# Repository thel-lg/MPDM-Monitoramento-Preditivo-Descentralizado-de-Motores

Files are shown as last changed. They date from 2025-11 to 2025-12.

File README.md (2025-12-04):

# MPDM - Monitoramento Preditivo de Motores Elétricos





Este repositório contém o firmware e documentação do **MPDM**, um sistema IOT desenvolvido como Trabalho de Conclusão de Curso (TCC) focado na Indústria 4.0 e Manutenção Preditiva.

O sistema realiza a leitura de grandezas físicas críticas de motores elétricos, transmite via LoRa (Long Range) e apresenta os dados em uma Interface Homem-Máquina (IHM) portátil com capacidade de armazenamento histórico.

## 👨‍💻 Equipe de Desenvolvimento

Este projeto foi desenvolvido por:
* **Gustavo Santana Nascimento**
* **Lucas Santos Gama**
* **Nicole da Silva Nunes Pitombeira**
* **Polyanna Silva Borges**

---

## 📐 Arquitetura do Sistema

O projeto é dividido em dois módulos baseados no microcontrolador ESP32:

### 1. Módulo Transmissor (Sensor Node)
Responsável pela aquisição de dados e transmissão sem fio.
* **Processamento:** Leitura de sensores e fusão de dados.
* **Estado:** Máquina de estados (Standby / Transmitting) para economia de energia.
* **Feedback:** LED RGB para indicação visual de status (Erro, Conexão, Leitura).

### 2. Módulo Receptor (Gateway/IHM)
Responsável pelo recebimento, processamento, exibição e armazenamento.
* **Interface:** Display TFT colorido com navegação por menus e gráficos em tempo real.
* **Datalogger:** Gravação de dados em Cartão SD (CSV) com timestamp preciso (RTC).
* **Diagnóstico:** Sistema de alertas visuais e sonoros para falhas de hardware (LoRa, RTC, SD).

## 🛠 Hardware e Componentes

### Sensores e Atuadores
* **Microcontrolador:** ESP32 (DevKit V1)
* **Vibração/Acelerômetro:** BMI160 (Eixos X, Y, Z e RMS)
* **Corrente AC:** SCT-013 (Não invasivo)
* **Temperatura:** DS18B20 (Blindado)
* **Comunicação:** Módulos LoRa SX1278 (433MHz)
* **Armazenamento:** Módulo Micro SD Card SPI
* **Relógio de Tempo Real:** RTC DS3231 (I2C)
* **Display:** TFT 1.8" ST7735 (SPI)

### Pinagem Principal (Definições)

| Componente | Transmissor (GPIO) | Receptor (GPIO) |
| :--- | :--- | :--- |
| **LoRa (SS/RST/DIO0)** | 5 / 17 / 16 | 5 / 17 / 16 |
| **SPI (SCK/MISO/MOSI)** | Padrão VSPI | 18 / 19 / 23 |
| **Display (CS/DC/RST)** | N/A | 15 / 4 / 25 |
| **SD Card (CS)** | N/A | 13 |
| **I2C (SDA/SCL)** | 21 / 22 | 21 / 22 |
| **LEDs Status / Buzzer** | 25, 26, 33 | 14 (Buzzer) |

## 💻 Funcionalidades do Firmware

### Transmissor
* Leitura de sensores com tratamento de erros (`StatusType Enum`).
* Priorização de status via LED RGB (Azul=TX, Vermelho=Erro, Verde=OK).
* Protocolo de envio de estrutura binária (`struct DadosSensores`) para otimizar o payload LoRa.

### Receptor
* **Menu Interativo:** Navegação por botões físicos (Set, Dir, Esq/Analog).
* **Monitoramento de Saúde:** Watchdog via software para LoRa, RTC e SD Card.
* **Algoritmo de Suavização:** Filtro Exponencial (Alpha 0.8) para estabilização de leitura.
* **Calibração:** Modo dedicado para tara de sensores de vibração e corrente.
* **Segurança:** Sistema de arquivos robusto (`iniciarSDCard_Seguro`) para evitar corrupção de dados.

## 📚 Bibliotecas Utilizadas

* `LoRa` (Sandeep Mistry)
* `Adafruit_GFX` & `Adafruit_ST7735`
* `RTClib` (Adafruit)
* `SPI` & `Wire` (Nativas)
* `SD` & `FS` (Nativas ESP32)

## 🚀 Como Executar

1.  Instale o **Arduino IDE** ou **PlatformIO**.
2.  Instale as bibliotecas listadas acima via Gerenciador de Bibliotecas.
3.  Configure a placa como "DOIT ESP32 DEVKIT V1".
4.  Carregue o código da pasta `/Transmissor` no módulo sensor.
5.  Carregue o código da pasta `/Receptor` no módulo IHM.

---

## 🎓 Agradecimentos Especiais

Gostaríamos de agradecer a todos que tornaram este projeto possível:

* **Orientador:** Prof. Eduardo Félix Pereira, pela orientação técnica.
* **Professores:** Jurandir Sá dos Santos, Ronaldo Oliveira, Juliana da Silva e Sérgio Caldeira, pelo auxílio na elaboração técnica.
* **Escola SENAI “Mariano Ferraz”:** Pela infraestrutura e formação técnica.
* **Banca Examinadora:** Pela presença e pelas valiosas considerações.

---
*Projeto desenvolvido para fins acadêmicos - Curso Técnico em Eletroeletrônica - 2025.*

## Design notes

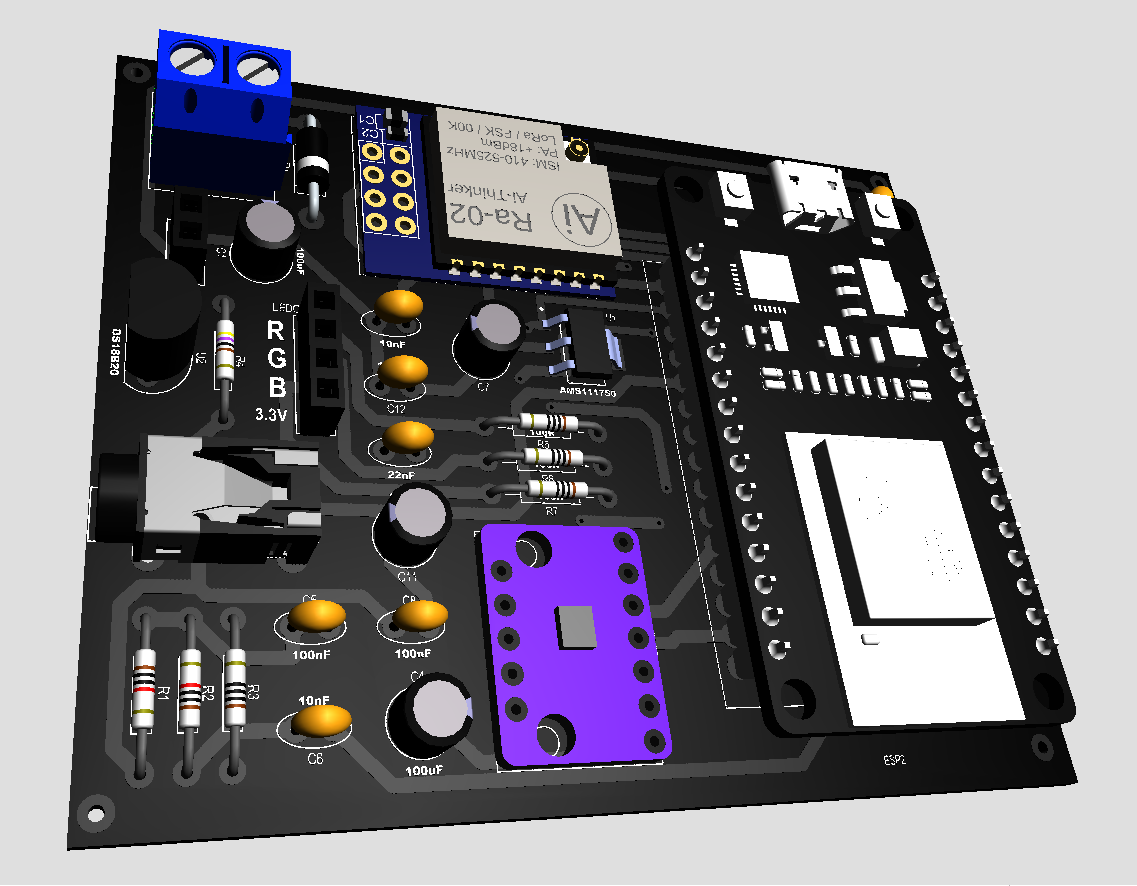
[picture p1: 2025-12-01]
Pci/Capturar.PNG

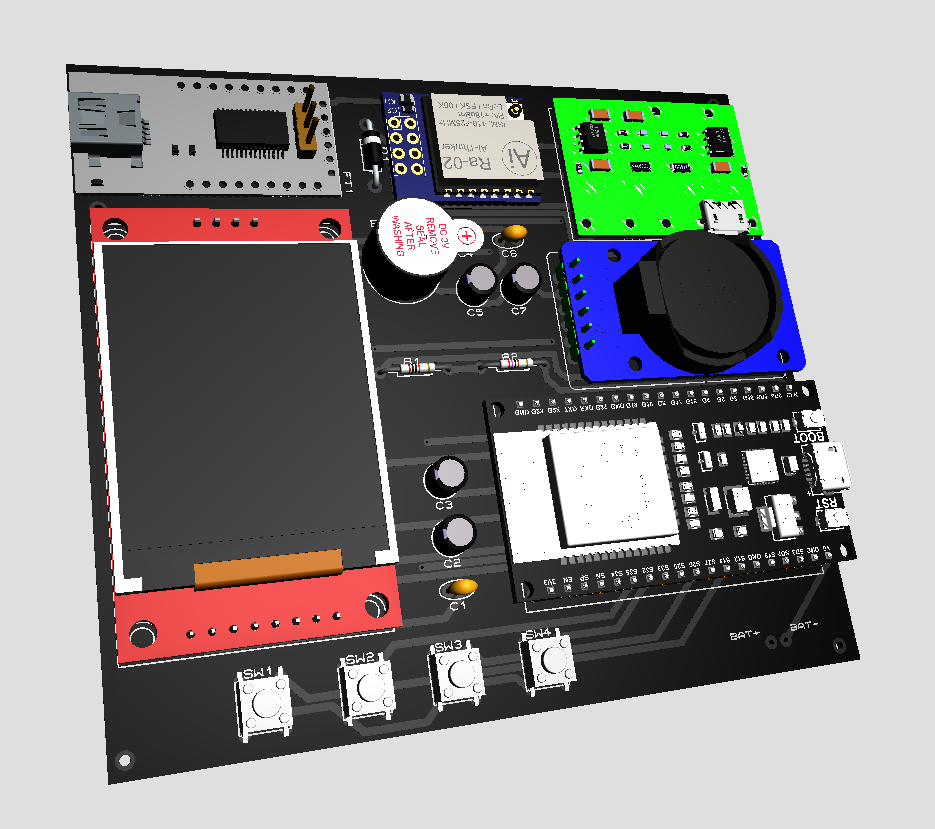
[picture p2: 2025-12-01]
Pci/CapturaQr.PNG

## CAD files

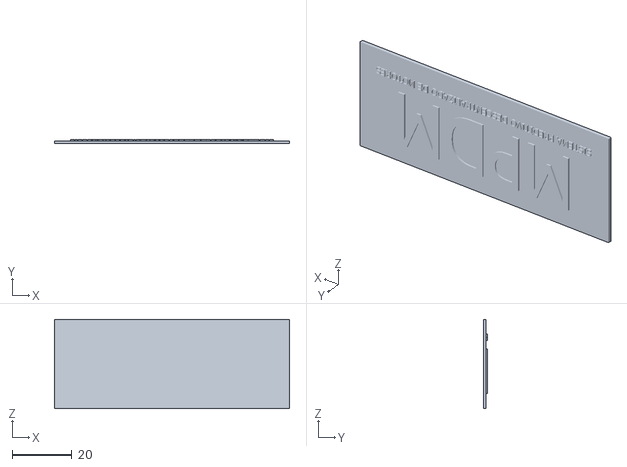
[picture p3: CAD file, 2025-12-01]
Cases3D/Case_Receptora/logoR.stl
79.0 x 1.50 x 30.0

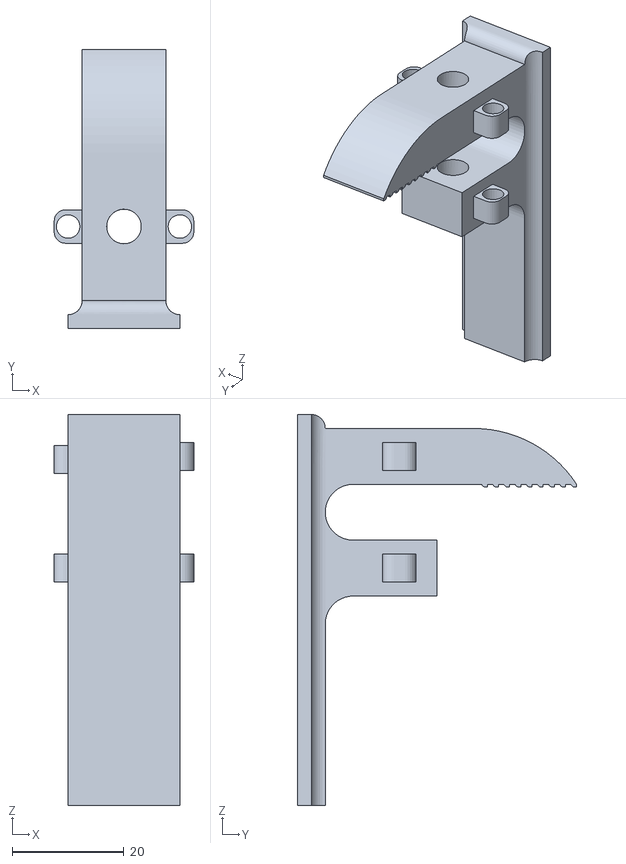
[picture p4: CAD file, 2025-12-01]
Cases3D/Case_Transmissora/Garra.stl
25.0 x 50.0 x 70.0

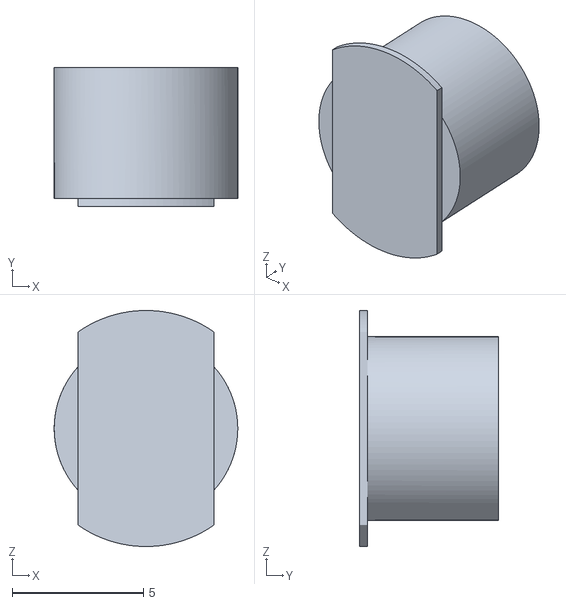
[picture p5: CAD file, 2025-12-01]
Cases3D/Case_Receptora/button.stl
7.00 x 5.30 x 9.00

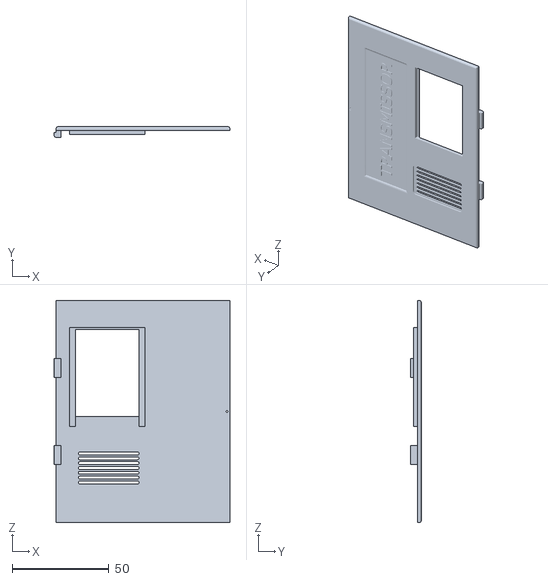
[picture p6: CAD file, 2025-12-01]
Cases3D/Case_Transmissora/Tampatransmissor.stl
91.0 x 5.50 x 115.0

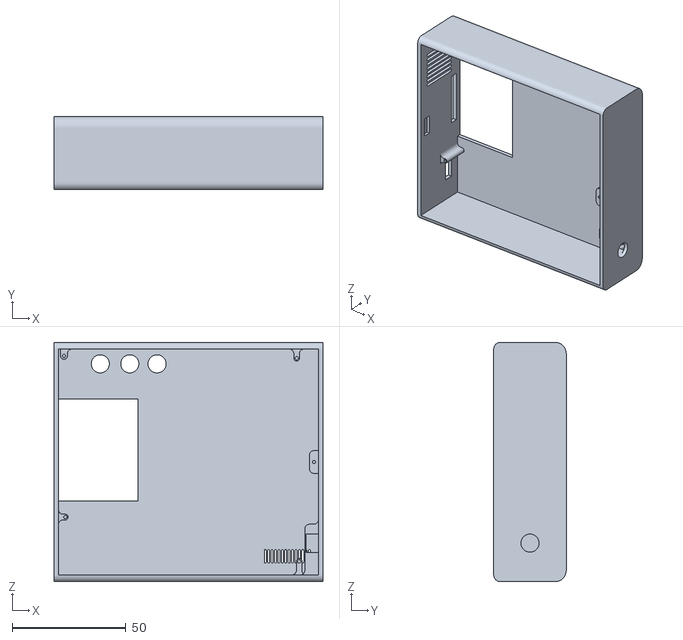
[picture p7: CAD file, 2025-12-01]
Cases3D/Case_Receptora/casereceptora.stl
118.5 x 32.0 x 105.5

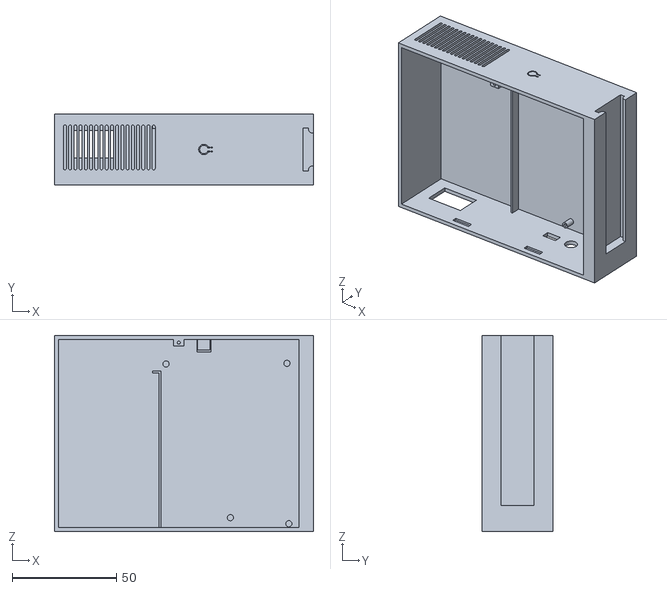
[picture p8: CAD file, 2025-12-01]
Cases3D/Case_Transmissora/transmissor.stl
124.0 x 34.0 x 94.0

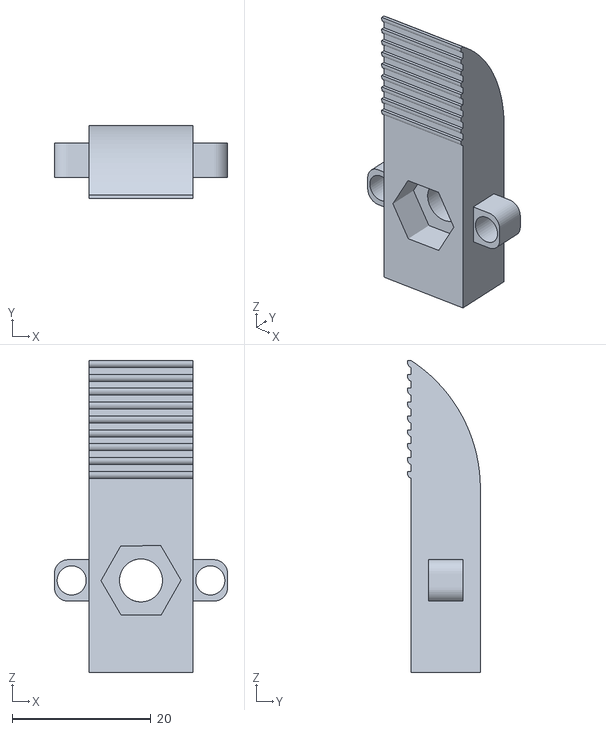
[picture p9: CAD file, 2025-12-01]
Cases3D/Case_Transmissora/garrasolta.stl
25.0 x 10.5 x 45.0

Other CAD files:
Cases3D/Case_Receptora/button.ipt
Cases3D/Case_Receptora/casereceptora.ipt
Cases3D/Case_Receptora/logoR.ipt
Cases3D/Case_Transmissora/Garra.ipt
Cases3D/Case_Transmissora/Pino.ipt
Cases3D/Case_Transmissora/Tampatransmissor.ipt
Cases3D/Case_Transmissora/garrasolta.ipt
Cases3D/Case_Transmissora/transmissor.ipt

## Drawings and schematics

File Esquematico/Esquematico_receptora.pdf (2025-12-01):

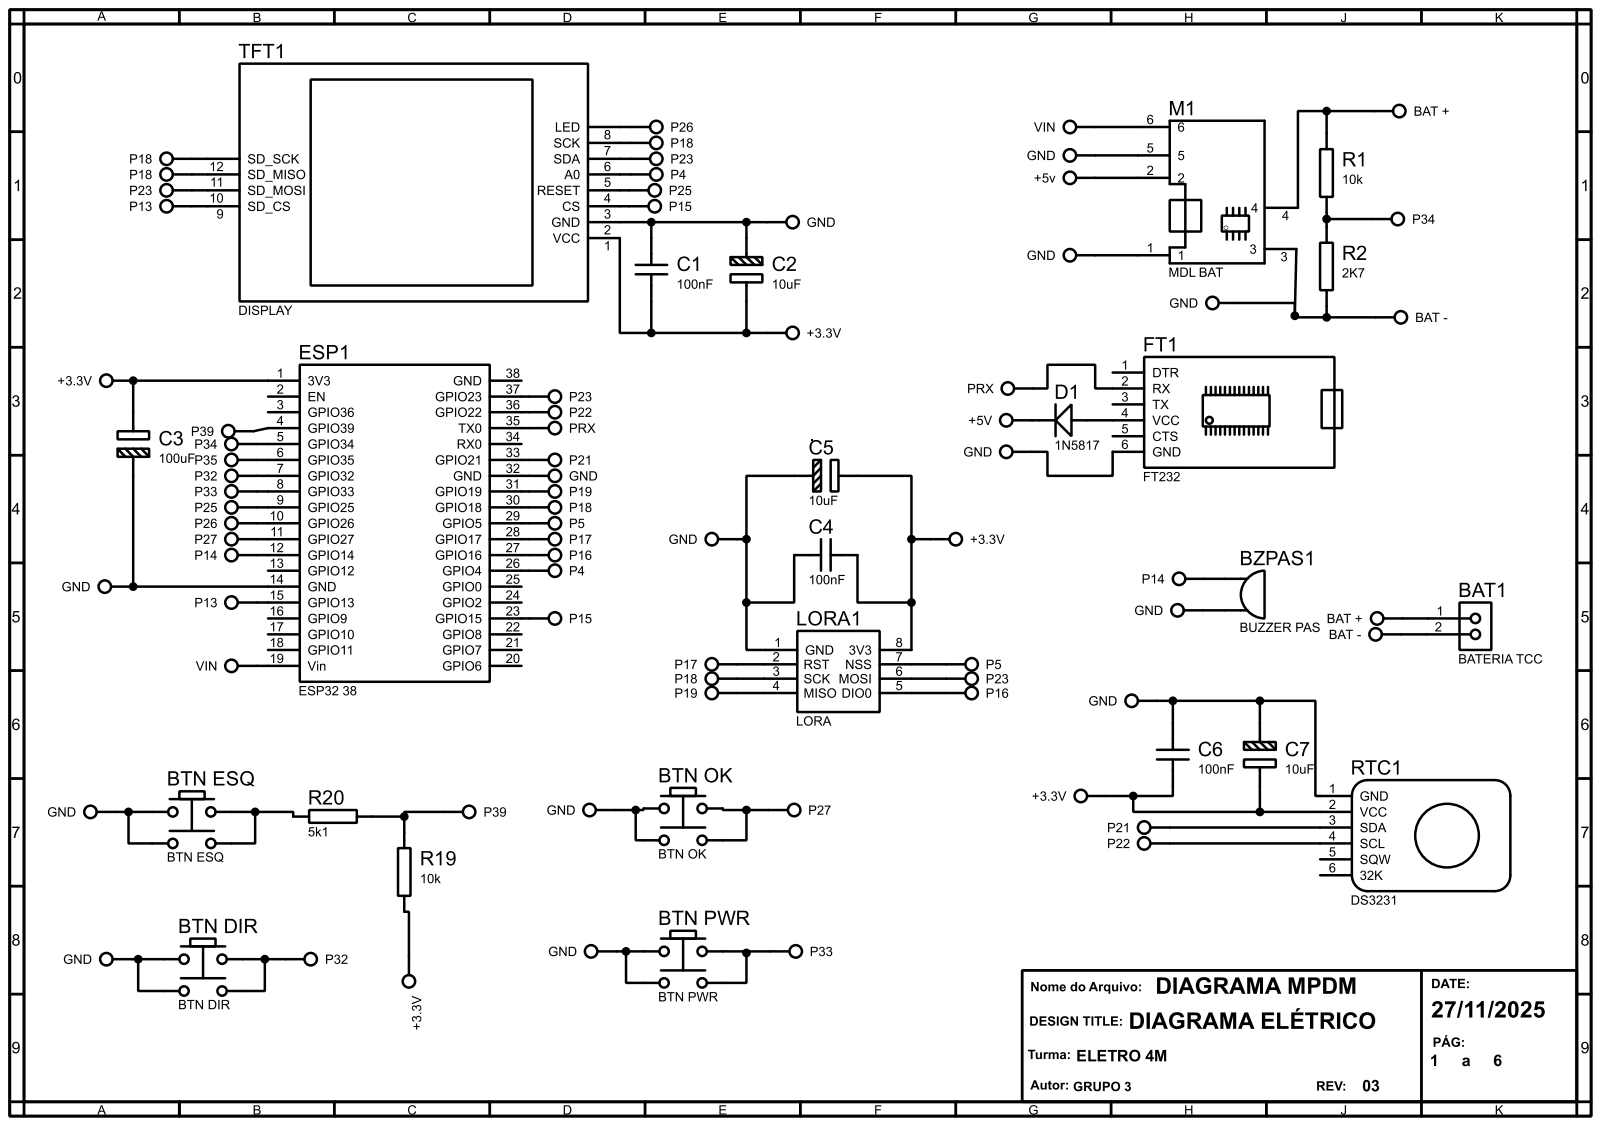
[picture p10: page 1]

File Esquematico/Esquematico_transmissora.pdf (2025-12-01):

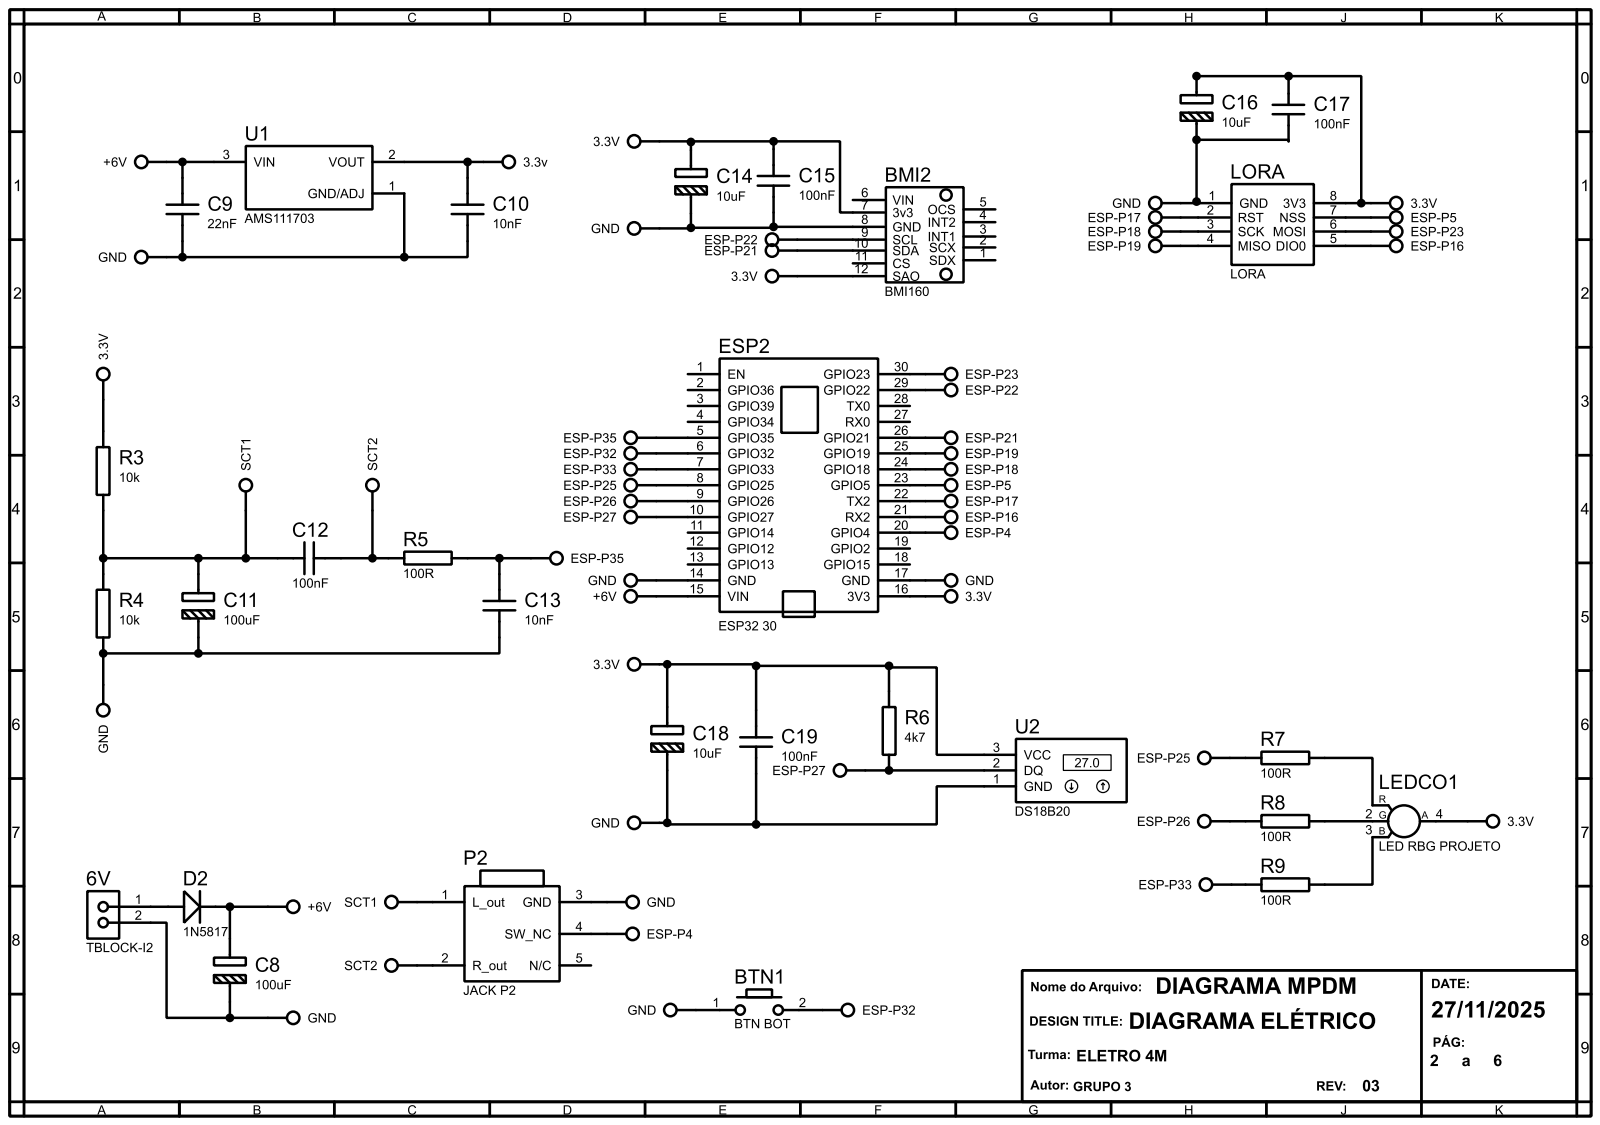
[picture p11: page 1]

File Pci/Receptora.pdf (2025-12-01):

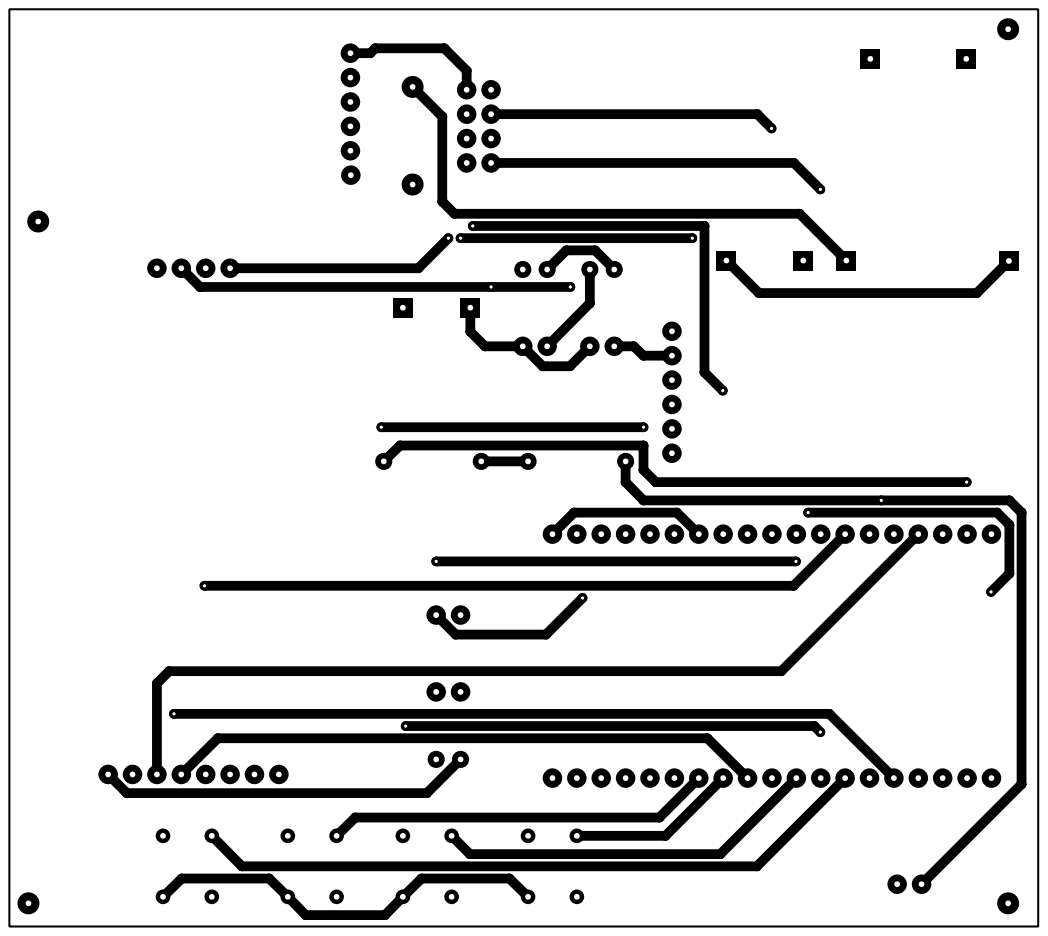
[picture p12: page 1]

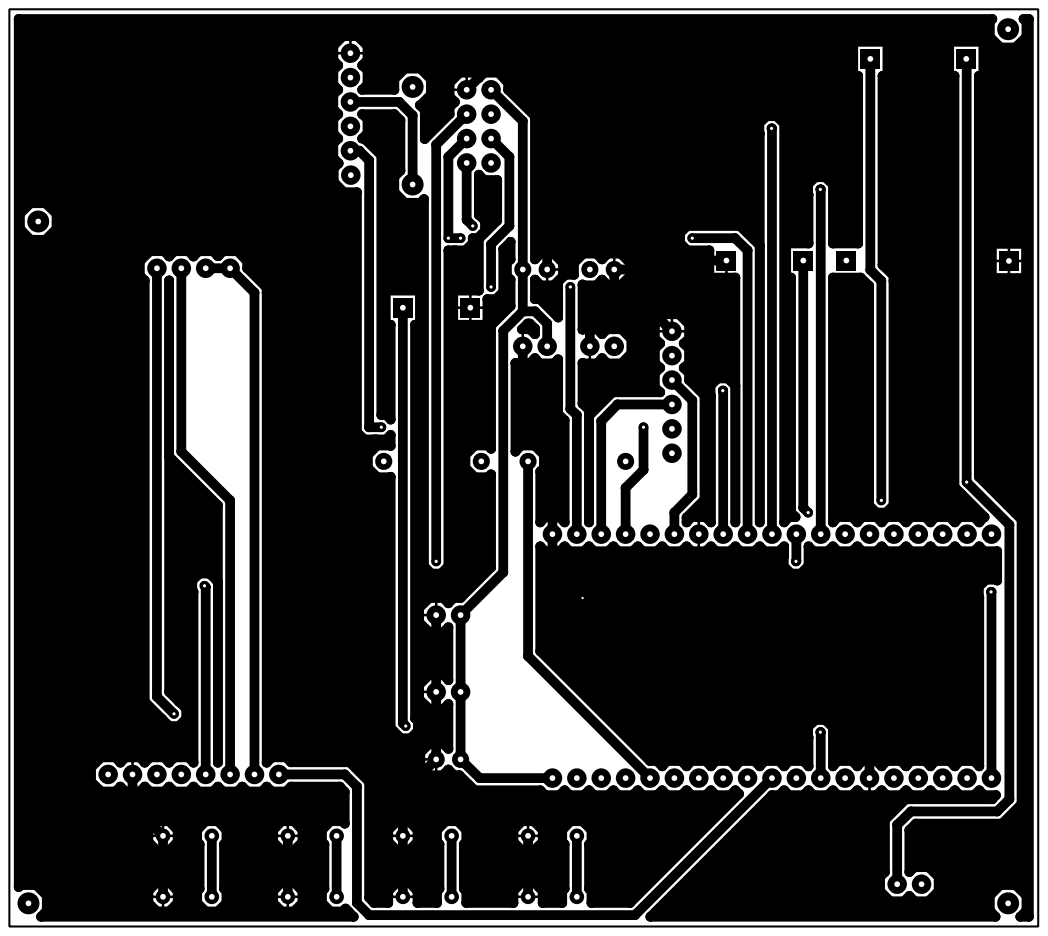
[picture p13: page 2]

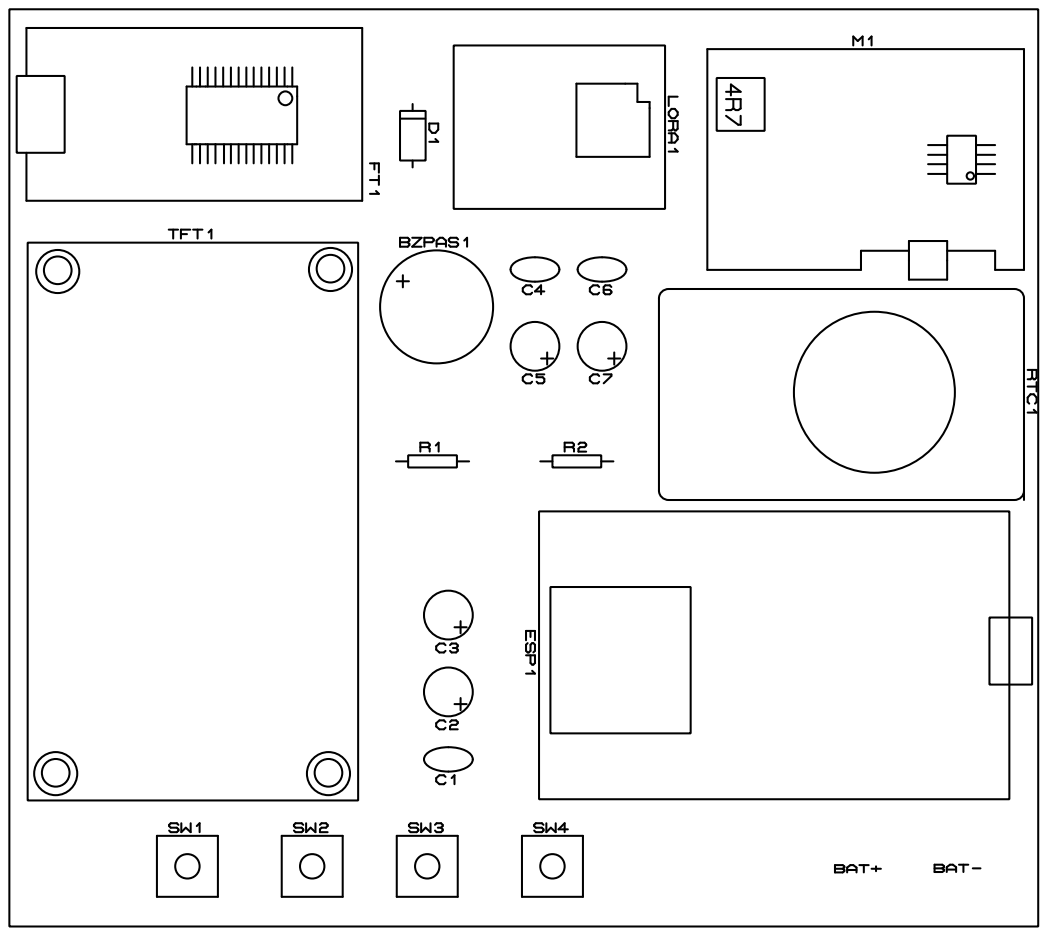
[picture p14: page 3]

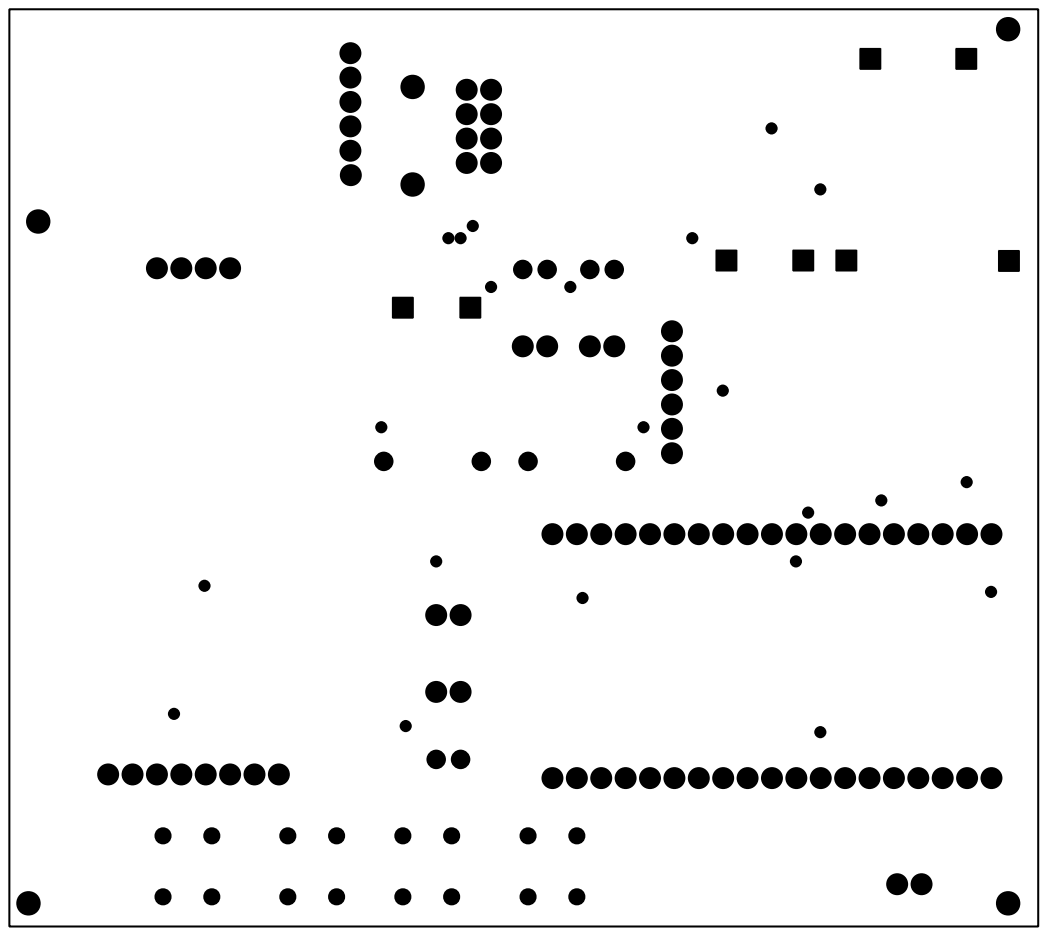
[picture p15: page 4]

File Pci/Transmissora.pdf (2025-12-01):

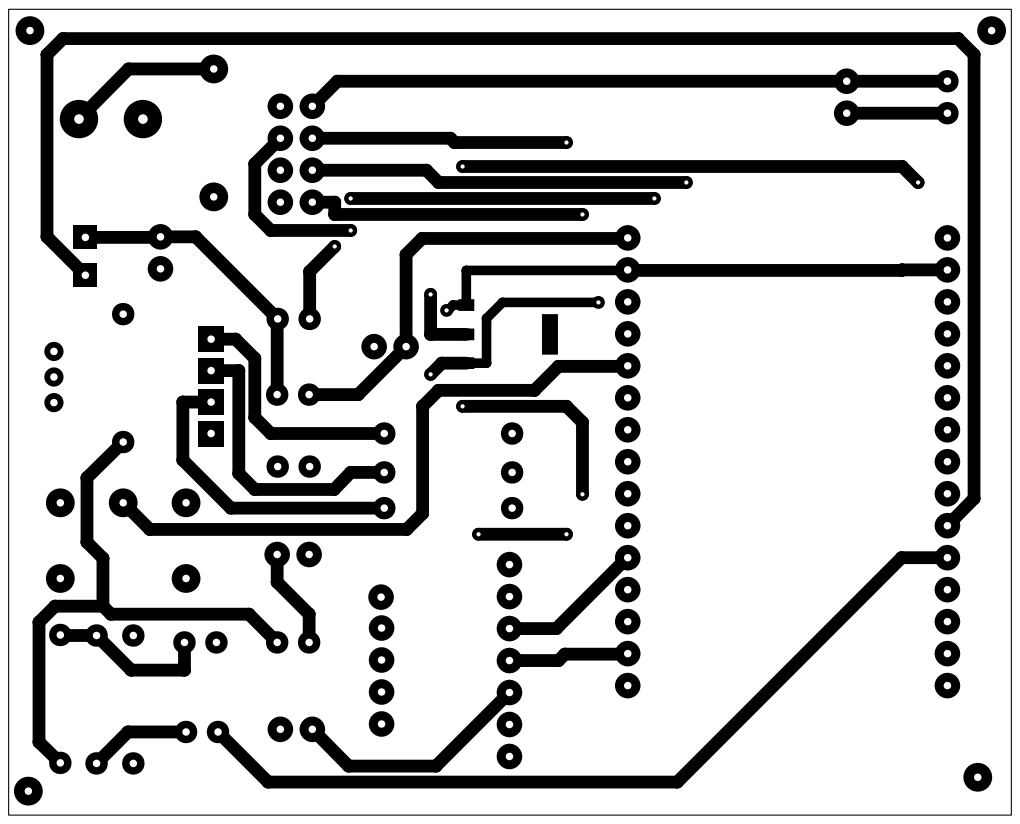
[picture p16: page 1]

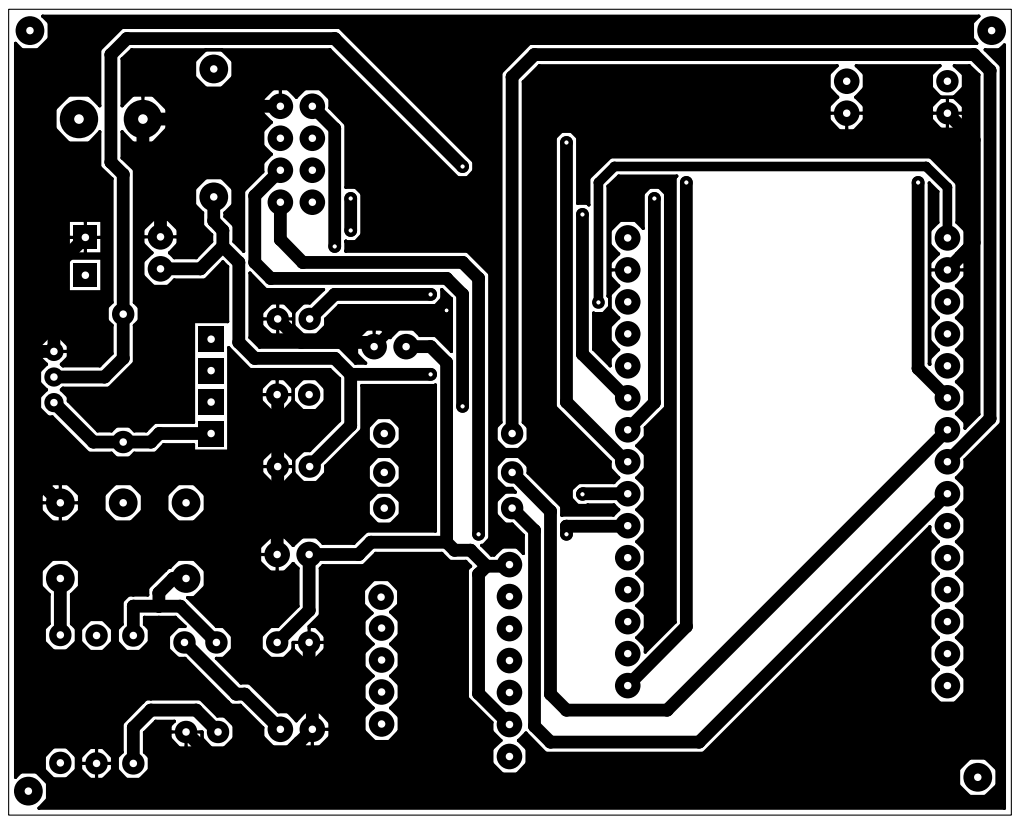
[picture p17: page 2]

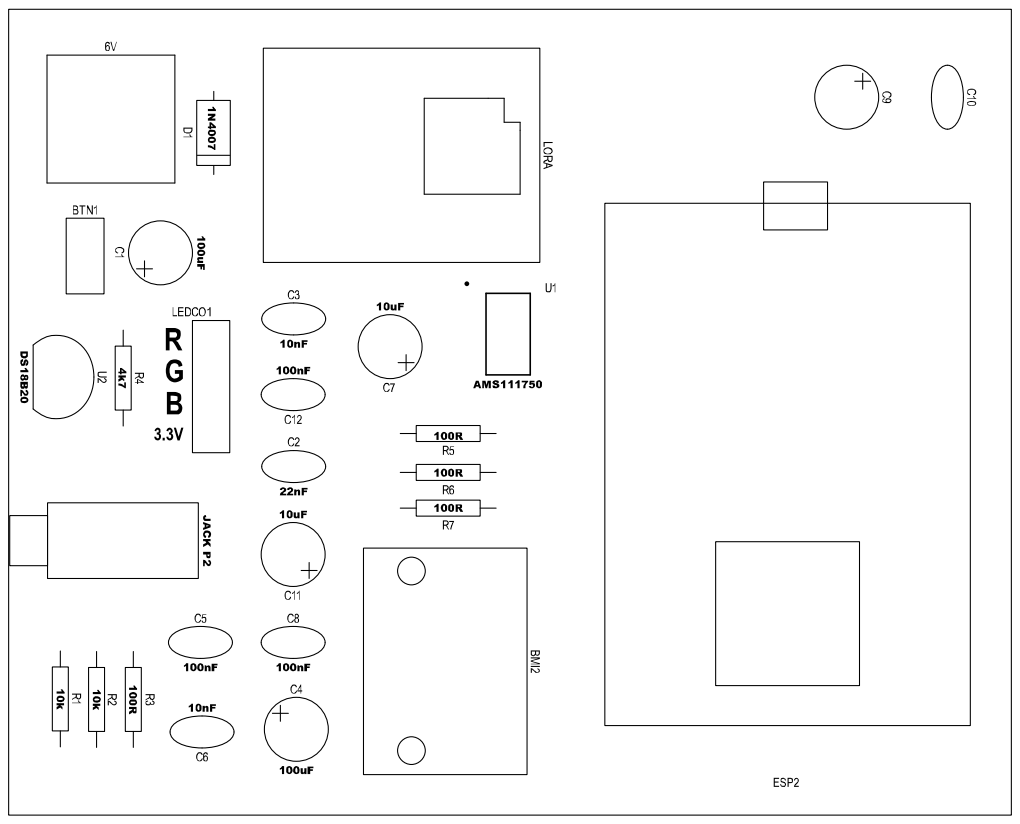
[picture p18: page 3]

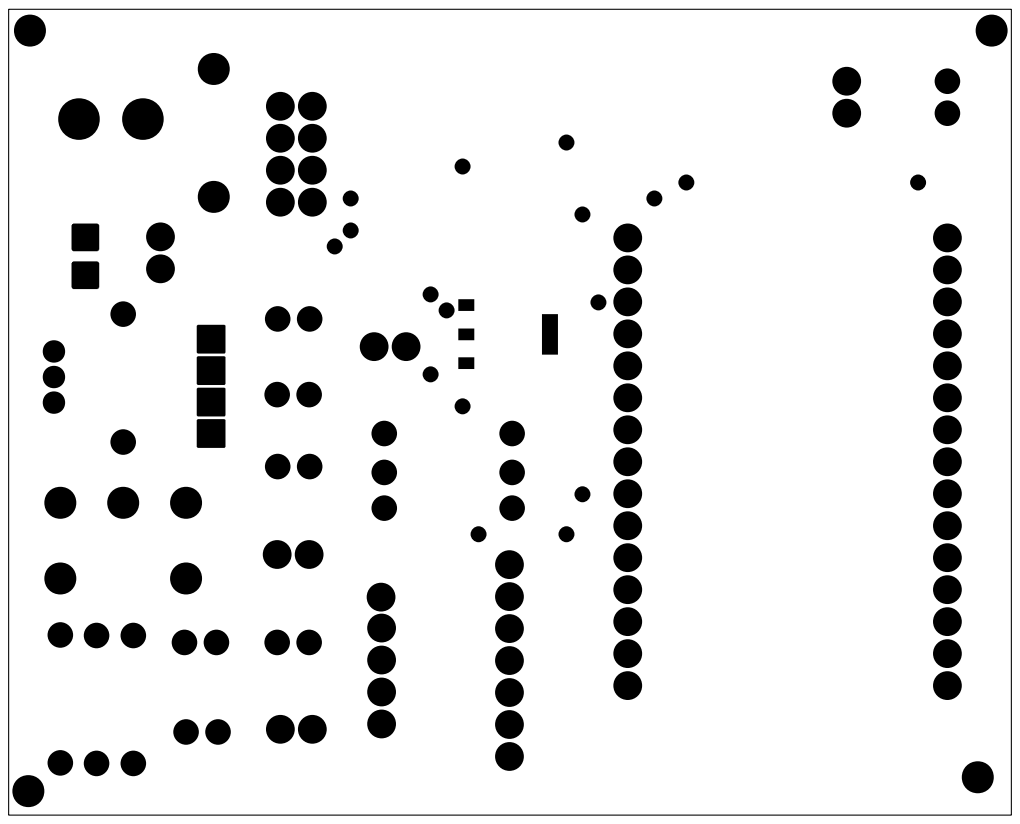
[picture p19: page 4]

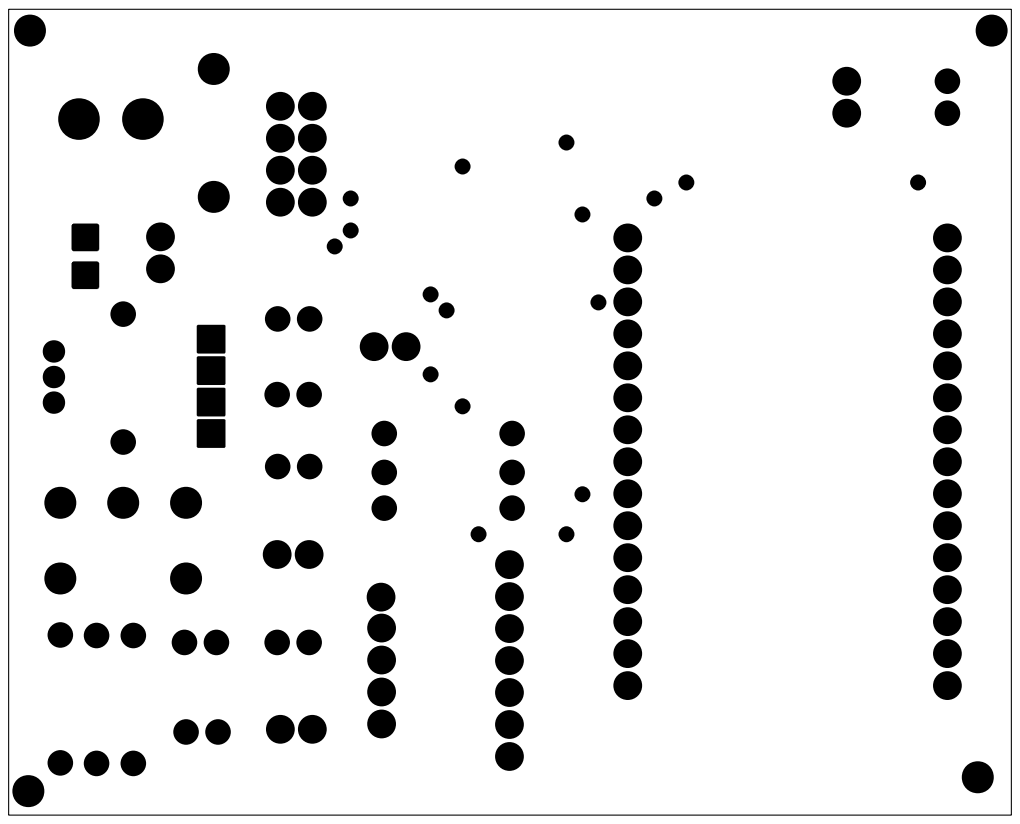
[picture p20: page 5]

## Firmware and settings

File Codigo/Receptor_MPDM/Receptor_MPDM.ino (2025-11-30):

#include <SPI.h>
#include <Wire.h>
#include <Adafruit_GFX.h>
#include <Adafruit_ST7735.h>
#include <RTClib.h>
#include <LoRa.h>
#include <SD.h>
#include <WiFi.h>
#include "esp_wifi.h"

// ESTRUTURA
struct DadosSensores {
    float corrente; float temperatura; float ax; float ay; float az;
};
DadosSensores dadosRecebidos;

// PINOS
#define LORA_SS    5
#define LORA_RST   17
#define LORA_DIO0  16
#define LORA_SCK   18
#define LORA_MOSI  23
#define LORA_MISO  19 

#define TFT_CS     15
#define TFT_DC     4
#define TFT_RST    25
const int TFT_LED    = 26;

const int BUZZER_PIN = 14;
const int BAT_PIN    = 34;
const int SD_CS_PIN  = 13; 

// BOTÕES
const int BOTAO_SET  = 27; 
const int BOTAO_PWR  = 33; 
const int BOTAO_DIR  = 32; // Digital
const int BOTAO_ESQ  = 39; // Analógico SN

// GLOBAIS
const long INTERVALO_GRAVACAO_SD = 15000;
const long INTERVALO_PACOTE_OK = 3000;      
const long INTERVALO_PACOTE_ATRASO = 10000; 
const int NUM_PONTOS_GRAFICO = 100;
const float ALPHA = 0.8; 
const bool DEBUG_LORA = true;
const long TIMEOUT_LORA = 300000; 

int falhaLoRaCount = 0;
int falhaRTCCount = 0;
int falhaSDCount = 0;
unsigned long lastSDTryMs = 0;
bool falhaHardwareLoRa = false;
const int MAX_RECOVERY_ATTEMPTS = 5; 

// Controle SD Seguro
bool sdCardOperacional = false;
bool falhaSD = false;
String erroSD = "OK";

bool sistemaLigado = true;
Adafruit_ST7735 tft = Adafruit_ST7735(TFT_CS, TFT_DC, TFT_RST);
RTC_DS3231 rtc;

String ultimoPacoteLoRaBruto = "Aguardando..."; 

float corrente = 0, temperatura = 0, vibracaoRMS = 0;
float eixoX = 0, eixoY = 0, eixoZ = 0;
float rssiLoRa = 0;
float padraoCorrente = 0, padraoVibracao = 0, padraoTemperatura = 0;
bool padroesDefinidos = false;
bool primeiraLeituraAposReset = true; 

// Navegação
int telaAtual = 1;
int appSelecionado = 1; 
int menuAjustesSelecionado = 0;
int menuPadroesSelecionado = 0;
int dadosSubTela = 0; 
int devMenuSelecionado = 0;
int devSubPagina = 0;
int devSDAcaoSelecionada = 0;
int scrollIndex = 0;

// Estado
bool emProcessoDeCalibracao = false;
unsigned long inicioCalibracaoMs = 0;
float somaCalibracaoI = 0, somaCalibracaoV = 0, somaCalibracaoT = 0;
int contadorCalibracao = 0;

bool falhaModuloVisivel = false;
bool falhaModuloAck = false; // IMUNIDADE DO POPUP
bool alertaAmareloAtivo = false; 
bool alertaVermelhoAtivo = false; 
unsigned long ultimoPacoteLoraMs = 0;
unsigned long ultimoTempoGravacaoSD = 0;
unsigned long lastUpdateMs = 0;

bool falhaLoRa = false;
bool falhaRTC = false;
String erroRTC = "OK";
String erroLoRa = "OK";

float historicoRMS[NUM_PONTOS_GRAFICO] = {0};
float historicoX[NUM_PONTOS_GRAFICO] = {0};
float historicoY[NUM_PONTOS_GRAFICO] = {0};
float historicoZ[NUM_PONTOS_GRAFICO] = {0};
int indiceHistorico = 0;
float tempMin = 0, tempMax = 0, corrMin = 0, corrMax = 0;

#include "Relogio.h"
#include "Display.h" 
#include "Calibracao.h"
#include "alerta.h"
#include "Cartao.h"
#include "bateria.h"

// --- FUNÇÕES ---
void bip(int duracao) {
    analogWrite(BUZZER_PIN, 20); delay(duracao); analogWrite(BUZZER_PIN, 0);
}

void destravarSPI() {
    digitalWrite(SD_CS_PIN, HIGH); delay(1);
}

bool lerBotaoDigital(int pino) {
  if (digitalRead(pino) == LOW) { delay(50); if (digitalRead(pino) == LOW) return true; }
  return false;
}

bool lerBotaoEsquerdaAnalogico() {
    long soma = 0;
    for(int i=0; i<3; i++) { soma += analogRead(BOTAO_ESQ); delay(2); }
    int leitura = soma / 3;
    if (leitura < 2500) return true; // Calibrado para 5k no SN
    return false;
}

bool iniciarLoRa(bool reset = false) {
    destravarSPI();
    if(reset) {
        LoRa.end();
        pinMode(LORA_RST, OUTPUT);
        digitalWrite(LORA_RST, LOW); delay(20);
        digitalWrite(LORA_RST, HIGH); delay(50);
    }
    LoRa.setPins(LORA_SS, LORA_RST, LORA_DIO0);
    if (!LoRa.begin(433E6)) {
        falhaLoRa = true; erroLoRa = "Nao encontrado"; 
        if(reset) falhaHardwareLoRa = true;
        return false;
    }
    LoRa.setSyncWord(0x12); LoRa.setSpreadingFactor(9); LoRa.setSignalBandwidth(125E3); LoRa.setCodingRate4(8);
    falhaLoRa = false; falhaHardwareLoRa = false; erroLoRa = "OK"; 
    return true;
}

void verificarSaudeModulos() {
  // 1. RTC
  if (!falhaRTC) { 
      bool rtcOk = rtc.now().year() >= 2024; 
      if (!rtcOk) { falhaRTC = true; erroRTC = "Data"; }
  }

  // 2. LoRa Watchdog
  unsigned long tempoDesdeUltimoPacote = millis() - ultimoPacoteLoraMs;
  
  if (tempoDesdeUltimoPacote <= INTERVALO_PACOTE_OK) {
      erroLoRa = "OK"; falhaLoRa = false;
  } 
  else if (tempoDesdeUltimoPacote <= INTERVALO_PACOTE_ATRASO) {
      erroLoRa = "Instavel"; falhaLoRa = false; 
  } 
  else {
      erroLoRa = "SEM SINAL"; falhaLoRa = true;
      // Mantém valores congelados conforme pedido
  }
  
  // 3. LÓGICA DO POPUP
  
  if(!falhaRTC && !falhaLoRa && !falhaSD) {
      falhaModuloAck = false; // Reset da imunidade (está saudável)
  }

  // Calcula se deve mostrar o pop-up AGORA
    bool temErroCritico = (falhaLoRa || falhaRTC || falhaSD);
  falhaModuloVisivel = temErroCritico && !falhaModuloAck;
}

void receberLoraBinario();

// SETUP
void setup() {
  Serial.begin(115200);
  delay(500);

  pinMode(BUZZER_PIN, OUTPUT); analogWrite(BUZZER_PIN, 0);
  pinMode(BOTAO_SET, INPUT_PULLUP); pinMode(BOTAO_PWR, INPUT_PULLUP);
  pinMode(BOTAO_DIR, INPUT_PULLUP); pinMode(BOTAO_ESQ, INPUT); 
  pinMode(BAT_PIN, INPUT);
  
  pinMode(SD_CS_PIN, OUTPUT); digitalWrite(SD_CS_PIN, HIGH); delay(10);

  SPI.begin(LORA_SCK, LORA_MISO, LORA_MOSI, LORA_SS);
  iniciarDisplay();

  telaInicialProfissional("Iniciando LoRa...", 0.25); iniciarLoRa(true);

  telaInicialProfissional("Verificando RTC...", 0.50); Wire.begin();
  if (!rtc.begin()) { falhaRTC = true; erroRTC = "FALHA I2C"; }
  else {
  
      //rtc.adjust(DateTime(2025, 11, 27, 8, 17, 0)); 
      if (rtc.lostPower() || rtc.now().year() < 2025) rtc.adjust(DateTime(F(__DATE__), F(__TIME__)));
      falhaRTC = false;
  }
  
  telaInicialProfissional("Montando SD...", 0.75);
  if (!iniciarSDCard_Seguro()) { 
      erroSD = "SD AUSENTE"; falhaSD = true;
  }

  WiFi.mode(WIFI_OFF); btStop();

  telaInicialProfissional("Sistema pronto!", 1.0);
  bip(50); delay(1000);
  
  desenharTelaAtual();
  ultimoPacoteLoraMs = millis(); 
}

// LOOP
void loop() {
  delay(10); 

  // Tenta ler LoRa antes de tudo
  destravarSPI();
  receberLoraBinario(); 

  // === LEITURA BOTÕES ===
  static unsigned long ultimoClique = 0;
  bool acaoBotao = false;
  
  if (millis() - ultimoClique > 200) { 
    bool curSet = lerBotaoDigital(BOTAO_SET); 
    bool curDir = lerBotaoDigital(BOTAO_DIR); 
    bool curEsq = false;
    if (lerBotaoEsquerdaAnalogico()) { delay(50); if (lerBotaoEsquerdaAnalogico()) curEsq = true; }

    // --- BOTÃO POWER (Lógica Independente) ---
    if (lerBotaoDigital(BOTAO_PWR)) {
        bip(50);
        sistemaLigado = !sistemaLigado;
        if (sistemaLigado) {
            ligarBacklight(140); telaInicialProfissional("Reiniciando...", 0.5);
            delay(500); telaAtual = 1; desenharTelaAtual(); ultimoPacoteLoraMs = millis();
        } else { telaDesligando(); }
        ultimoClique = millis();
        return; // Sai do loop
    }

    if (!sistemaLigado) { desligarBacklight(); tft.fillScreen(ST77XX_BLACK); return; }

    if (falhaModuloVisivel) {
            if (curSet) {
            bip(30);
            falhaModuloVisivel = false;
            falhaModuloAck = true; // IMUNIDADE ATIVADA!
            // Limpa a tela e volta pro menu
            tft.fillScreen(COR_FUNDO);
            desenharTelaAtual(); 
            ultimoClique = millis();
        }
        else {
             desenharPopupFalha();
        }
        return; 
    }

    // --- NAVEGAÇÃO NORMAL ---
    if (curEsq || curDir || curSet) {
        ultimoClique = millis(); 
        bip(30); 

        if (curSet) {
          if (telaAtual == 1) { 
            if (appSelecionado == 0) telaAtual = 0;
            else if (appSelecionado == 1) { telaAtual = 2; dadosSubTela = 0; }
            else if (appSelecionado == 2) telaAtual = 3;
            desenharTelaAtual();
          } else if (telaAtual == 3) { 
            if (menuAjustesSelecionado == 0) { telaAtual = 6; menuPadroesSelecionado = 0; }
            else if (menuAjustesSelecionado == 1) { telaAtual = 5; }
            else if (menuAjustesSelecionado == 2) { telaAtual = 4; devMenuSelecionado = 0; }
            desenharTelaAtual();
          } else if (telaAtual == 4) { 
            if (devMenuSelecionado == 0) { telaAtual = 7; devSubPagina = 0; }
            else if (devMenuSelecionado == 1) { telaAtual = 8; devSubPagina = 0; }
            else if (devMenuSelecionado == 2) { telaAtual = 9; devSubPagina = 0; devSDAcaoSelecionada = 0; }
            else if (devMenuSelecionado == 3) { toggleModoGrafico(); }
            desenharTelaAtual();
          } else if (telaAtual == 7 && devSubPagina == 1) { mostrarTelaReset("LoRa"); iniciarLoRa(true); ultimoPacoteLoraMs = millis(); desenharTelaAtual(); }
          else if (telaAtual == 8 && devSubPagina == 1) { mostrarTelaReset("RTC"); Wire.begin(); if(rtc.begin()){ falhaRTC=false; } desenharTelaAtual(); }
          else if (telaAtual == 9 && devSubPagina == 1) {
            if (devSDAcaoSelecionada == 0) { mostrarTelaReset("Cartao SD"); iniciarSDCard_Seguro(); }
            else if (devSDAcaoSelecionada == 1) { devSubPagina = 2; }
            desenharTelaAtual();
          } else if (telaAtual == 6) { 
            if (menuPadroesSelecionado == 0) { iniciarCalibracao(); }
            else if (menuPadroesSelecionado == 1) { iniciarResetPadroes(); }
          }
        } 
        else if (curEsq || curDir) {
            // Lógica de Navegação Padrão
            if (telaAtual == 1) {
                if (curDir) appSelecionado = (appSelecionado < 2) ? appSelecionado + 1 : 0;
                if (curEsq) appSelecionado = (appSelecionado > 0) ? appSelecionado - 1 : 2;
            }
            else if (telaAtual == 2) {
                if (curDir) dadosSubTela = (dadosSubTela < 2) ? dadosSubTela + 1 : 0;
                if (curEsq) { if (dadosSubTela == 0) telaAtual = 1; else dadosSubTela--; }
            }
            else if (telaAtual == 3) {
                if (curDir) menuAjustesSelecionado = (menuAjustesSelecionado < 2) ? menuAjustesSelecionado + 1 : 0;
                if (curEsq) telaAtual = 1; 
            }
            else if (telaAtual == 4 || telaAtual == 5 || telaAtual == 6) {
                  if (curEsq) telaAtual = 3; 
                  if (curDir) {
                    if(telaAtual == 4) devMenuSelecionado = (devMenuSelecionado < 3) ? devMenuSelecionado + 1 : 0;
                    if(telaAtual == 6) menuPadroesSelecionado = (menuPadroesSelecionado < 1) ? menuPadroesSelecionado + 1 : 0;
                  }
            }
            else if (telaAtual > 6) {
                if (curEsq) { if (devSubPagina > 0) devSubPagina--; else telaAtual = 4; } 
                if (curDir) {
                    if (devSubPagina == 0) devSubPagina = 1;
                    else if (telaAtual == 9 && devSubPagina == 1) devSDAcaoSelecionada = (devSDAcaoSelecionada < 1) ? devSDAcaoSelecionada + 1 : 0;
                }
            }
            else { if (curEsq) telaAtual = 1; }
            
            destravarSPI();
            desenharTelaAtual();
        }
    }
  }

  if (emProcessoDeCalibracao) {
    if (millis() - inicioCalibracaoMs < 60000UL) {
      desenharTelaCalibracao((float)(millis() - inicioCalibracaoMs) / 60000.0f);
    } else { finalizarCalibracao(); }
  }

  // Atualizações periódicas (Só se não estiver no popup)
  if (millis() - lastUpdateMs > 500 && !emProcessoDeCalibracao) {
      lastUpdateMs = millis();
      verificarSaudeModulos(); // Atualiza status
      destravarSPI();
      
      if (!falhaModuloVisivel) { // Só desenha tela normal se não tiver falha visível
          atualizarTela(); 
      }
      verificarAlertas(); // Som
  }

  if (millis() - ultimoTempoGravacaoSD > INTERVALO_GRAVACAO_SD) {
    ultimoTempoGravacaoSD = millis();
    gravarSD_Seguro(); 
  }
}

void receberLoraBinario() {
    int packetSize = LoRa.parsePacket();
    if (packetSize == sizeof(DadosSensores)) {
        LoRa.readBytes((uint8_t*)&dadosRecebidos, sizeof(DadosSensores));
        rssiLoRa = LoRa.packetRssi(); 
        ultimoPacoteLoraMs = millis();
        falhaLoRa = false; erroLoRa = "OK";

        ultimoPacoteLoRaBruto = String("I:") + String(dadosRecebidos.corrente, 2) + " T:" + String(dadosRecebidos.temperatura, 1);

        float r_bruto = sqrt(dadosRecebidos.ax*dadosRecebidos.ax + dadosRecebidos.ay*dadosRecebidos.ay + dadosRecebidos.az*dadosRecebidos.az);

        if (primeiraLeituraAposReset) {
            corrente = dadosRecebidos.corrente;
            temperatura = dadosRecebidos.temperatura;
            eixoX = dadosRecebidos.ax;
            eixoY = dadosRecebidos.ay;
            eixoZ = dadosRecebidos.az;
            vibracaoRMS = r_bruto;
            primeiraLeituraAposReset = false;
            corrMin = corrMax = corrente;
            tempMin = tempMax = temperatura;
        } else {
            corrente = (ALPHA * dadosRecebidos.corrente) + ((1.0 - ALPHA) * corrente);
            temperatura = (ALPHA * dadosRecebidos.temperatura) + ((1.0 - ALPHA) * temperatura);
            eixoX = (ALPHA * dadosRecebidos.ax) + ((1.0 - ALPHA) * eixoX);
            eixoY = (ALPHA * dadosRecebidos.ay) + ((1.0 - ALPHA) * eixoY);
            eixoZ = (ALPHA * dadosRecebidos.az) + ((1.0 - ALPHA) * eixoZ);
            vibracaoRMS = (ALPHA * r_bruto) + ((1.0 - ALPHA) * vibracaoRMS);
            
            if (corrente > corrMax) corrMax = corrente;
            if (corrente < corrMin) corrMin = corrente;
            if (temperatura > tempMax) tempMax = temperatura;
            if (temperatura < tempMin) tempMin = temperatura;
        }
        if(emProcessoDeCalibracao) atualizarSomaCalibracao();
        historicoX[indiceHistorico] = eixoX; historicoY[indiceHistorico] = eixoY;
        historicoZ[indiceHistorico] = eixoZ; historicoRMS[indiceHistorico] = vibracaoRMS;
        indiceHistorico = (indiceHistorico + 1) % NUM_PONTOS_GRAFICO;
        Serial.printf("RX;%.2f;%.1f;%.2f\n", corrente, temperatura, vibracaoRMS);
    }
}

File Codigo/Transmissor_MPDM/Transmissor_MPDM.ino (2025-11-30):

// ======================================================================
// TRANSMISSOR FINAL 
// ======================================================================

#include <LoRa.h>
#include <WiFi.h>
#include "esp_bt.h"
#include <Wire.h> 

// Estrutura 
struct DadosSensores {
    float corrente;
    float temperatura;
    float ax;
    float ay;
    float az;
};

enum StatusType { STATUS_OK, STATUS_ERRO_IMU, STATUS_ERRO_TEMP, STATUS_ERRO_CORRENTE, STATUS_ERRO_LORA };

// Includes
#include "sensor_bmi160.h"
#include "sensor_ds18b20.h"
#include "sensor_sct013.h"

#define BOTAO_INICIAR_PIN 32 
#define LED_R_PIN 25
#define LED_G_PIN 26
#define LED_B_PIN 33

#define LORA_SS 5
#define LORA_RST 17
#define LORA_DIO0 16

enum SystemState { STANDBY, TRANSMITTING };
SystemState systemState = STANDBY;

DadosSensores dadosAtuais;
bool lora_ok = false;

// Status LED
StatusType errosAtivos[5];
int totalDeErros = 0;
int indiceDoErroAtual = 0;
unsigned long ultimoTempoPiscada = 0; 
bool ledPiscandoApagado = false; 

const long INTERVALO_ENVIO_LORA = 1000;
unsigned long timerLoRa = 0;

void setLedColor(bool red, bool green, bool blue) {
    digitalWrite(LED_R_PIN, red ? LOW : HIGH);
    digitalWrite(LED_G_PIN, green ? LOW : HIGH);
    digitalWrite(LED_B_PIN, blue ? LOW : HIGH);
}

void setup_led_status() {
    pinMode(LED_R_PIN, OUTPUT); pinMode(LED_G_PIN, OUTPUT); pinMode(LED_B_PIN, OUTPUT);
    setLedColor(false, false, false); 
}

void gerenciarLedDeStatus(const DadosSensores &dados) {
    // 1. AZUL (Prioridade Total)
    if (systemState == TRANSMITTING) {
        setLedColor(false, false, true); return; 
    }
    // 2. ERRO
    if (totalDeErros > 0) {
        if (millis() - ultimoTempoPiscada > 800) {
            ultimoTempoPiscada = millis();
            if (ledPiscandoApagado) {
                setLedColor(false, false, false); 
                indiceDoErroAtual = (indiceDoErroAtual + 1) % totalDeErros;
                ledPiscandoApagado = false;
            } else {
                StatusType erro = errosAtivos[indiceDoErroAtual];
                if(erro == STATUS_ERRO_CORRENTE) setLedColor(true, true, true); // Branco
                else if(erro == STATUS_ERRO_TEMP) setLedColor(false, true, true); // Ciano
                else setLedColor(true, false, false); // Vermelho
                ledPiscandoApagado = true;
            }
        }
        return; 
    }
    // 3. OK / CARGA
    if (dados.corrente > 0.15) {
        if (millis() - ultimoTempoPiscada > 100) {
            ultimoTempoPiscada = millis();
            setLedColor(false, !digitalRead(LED_G_PIN), false); // Pisca Verde
        }
    } else {
        setLedColor(false, true, false); // Verde Fixo
    }
}

void setup_lora() {
    LoRa.setPins(LORA_SS, LORA_RST, LORA_DIO0);
    if (!LoRa.begin(433E6)) {
        lora_ok = false; return;
    }
    // --- CONFIGURAÇÃO DE ALCANCE  ---
    LoRa.setTxPower(20);
    LoRa.setSyncWord(0x12);
    LoRa.setSpreadingFactor(9); // SF9 (Balanço alcance/velocidade)
    LoRa.setSignalBandwidth(125E3); // 125kHz (Mais estável que 62.5k)
    LoRa.setCodingRate4(8);
    lora_ok = true;
}

void setup() {
    Serial.begin(115200);
    Wire.begin(); WiFi.mode(WIFI_OFF); btStop();
    pinMode(BOTAO_INICIAR_PIN, INPUT_PULLUP); 
    setup_led_status();
    setup_bmi160(); setup_ds18b20(); setup_sct013(); 
    setup_lora(); 
}

void loop() {
    // Leitura
    bool imu_ok = loop_bmi160(dadosAtuais);
    bool temp_ok = loop_ds18b20(dadosAtuais);
    bool current_ok = loop_sct013(dadosAtuais);
    
    totalDeErros = 0;
    if (!lora_ok) errosAtivos[totalDeErros++] = STATUS_ERRO_LORA;
    if (!imu_ok) errosAtivos[totalDeErros++] = STATUS_ERRO_IMU;
    if (!temp_ok) errosAtivos[totalDeErros++] = STATUS_ERRO_TEMP;
    if (!current_ok) errosAtivos[totalDeErros++] = STATUS_ERRO_CORRENTE;

    // Botão
    static int lastBtn = HIGH;
    static unsigned long dbBtn = 0;
    int leituraBtn = digitalRead(BOTAO_INICIAR_PIN); 
    if (leituraBtn == LOW && lastBtn == HIGH) {
        if ((millis() - dbBtn) > 300) {
            dbBtn = millis();
            systemState = (systemState == STANDBY) ? TRANSMITTING : STANDBY;
        }
    }
    lastBtn = leituraBtn;

    // Transmissão
    if (systemState == TRANSMITTING) {
        if (millis() - timerLoRa > INTERVALO_ENVIO_LORA) {
            timerLoRa = millis();
            if(lora_ok) {
                LoRa.beginPacket();
                LoRa.write((uint8_t*)&dadosAtuais, sizeof(DadosSensores));
                LoRa.endPacket();
                Serial.println("TX OK");
            } else {
                setup_lora(); // Tenta reviver
            }
        }
    }
    gerenciarLedDeStatus(dadosAtuais);
}

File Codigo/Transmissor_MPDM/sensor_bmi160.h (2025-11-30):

#ifndef SENSOR_BMI160_H
#define SENSOR_BMI160_H

#include <Wire.h>
#include <DFRobot_BMI160.h>

const int8_t BMI160_ADDR_CUSTOM = 0x69; 
const float ACCEL_SENSITIVITY = 16384.0;

unsigned long ultimoTempoLeitura_bmi = 0;
const unsigned long intervaloLeitura_bmi = 50; 
DFRobot_BMI160 bmi160;

const int NUM_AMOSTRAS = 20; 
float amostras_ax[NUM_AMOSTRAS] = {0};
float amostras_ay[NUM_AMOSTRAS] = {0};
float amostras_az[NUM_AMOSTRAS] = {0};
int indice_amostra = 0;
float ACCEL_OFFSET_X = 0.0, ACCEL_OFFSET_Y = 0.0, ACCEL_OFFSET_Z = 0.0;
static bool statusBmiOk = true;

void setup_bmi160() {
    // Inicializa a primeira vez
    if (bmi160.I2cInit(BMI160_ADDR_CUSTOM) != BMI160_OK) {
        // Se falhar, não trava o boot, apenas marca erro silencioso
        // O loop vai tentar recuperar depois
    } else {
        // Se iniciou, calibra o offset (média de 50 leituras)
        int16_t d[3];
        float tx = 0, ty = 0, tz = 0;
        for (int i = 0; i < 50; i++) {
            if (bmi160.getAccelData(d) == BMI160_OK) {
                 tx += d[0]; ty += d[1]; tz += d[2];
            }
            delay(5);
        }
        ACCEL_OFFSET_X = (tx / 50.0) / ACCEL_SENSITIVITY * 9.8;
        ACCEL_OFFSET_Y = (ty / 50.0) / ACCEL_SENSITIVITY * 9.8;
        ACCEL_OFFSET_Z = (tz / 50.0) / ACCEL_SENSITIVITY * 9.8; 
    }
}

bool loop_bmi160(DadosSensores &dados) {
    if (millis() - ultimoTempoLeitura_bmi < intervaloLeitura_bmi) {
        return statusBmiOk; 
    }
    ultimoTempoLeitura_bmi = millis();

    // --- MECÂNICA DE AUTO-RECUPERAÇÃO (Heartbeat) ---
    // 1. Testa se o dispositivo responde no barramento I2C
    Wire.beginTransmission(BMI160_ADDR_CUSTOM);
    if (Wire.endTransmission() != 0) {
        // Dispositivo sumiu ou travou o I2C
        // Tenta reinicializar a biblioteca (Soft Reconnect)
        if (bmi160.I2cInit(BMI160_ADDR_CUSTOM) != BMI160_OK) {
            statusBmiOk = false;
            dados.ax = 0; dados.ay = 0; dados.az = 0; // Zera pra não mostrar valor velho
            return false; // Marca erro (Vermelho se estiver em Standby)
        }
    }

    // 2. Tenta ler os dados
    int16_t d[3];
    if (bmi160.getAccelData(d) == BMI160_OK) {
        
        // Se leu, converte
        float fx = (d[0] / ACCEL_SENSITIVITY * 9.8) - ACCEL_OFFSET_X;
        float fy = (d[1] / ACCEL_SENSITIVITY * 9.8) - ACCEL_OFFSET_Y;
        float fz = (d[2] / ACCEL_SENSITIVITY * 9.8) - ACCEL_OFFSET_Z + 9.8;

        // Verifica se está congelado em ZERO exato (muito raro acontecer nos 3 eixos ao mesmo tempo)
        // Se estiver tudo zero absoluto, pode ser falha de leitura da lib
        if (d[0] == 0 && d[1] == 0 && d[2] == 0) {
             // Considera suspeito, mas não falha total ainda, espera a próxima
        }

        // Média Móvel
        amostras_ax[indice_amostra] = fx;
        amostras_ay[indice_amostra] = fy;
        amostras_az[indice_amostra] = fz;
        indice_amostra = (indice_amostra + 1) % NUM_AMOSTRAS;
        
        float sx = 0, sy = 0, sz = 0;
        for (int i = 0; i < NUM_AMOSTRAS; i++) {
            sx += amostras_ax[i]; sy += amostras_ay[i]; sz += amostras_az[i];
        }
        dados.ax = sx / NUM_AMOSTRAS;
        dados.ay = sy / NUM_AMOSTRAS;
        dados.az = sz / NUM_AMOSTRAS; 

        statusBmiOk = true;
        return true;
    }
    
    // Se falhou a leitura da lib
    statusBmiOk = false;
    return false;
}
#endif

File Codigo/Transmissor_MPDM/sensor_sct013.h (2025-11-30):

#ifndef SENSOR_SCT013_H
#define SENSOR_SCT013_H

struct DadosSensores;

// --- PINOS ---
#define PINO_DETECCAO_SCT 4       
#define PINO_SENSOR_CORRENTE 35
#define AMOSTRAS_RMS 2000         

// --- CALIBRAÇÃO ---
#define VREF_ESP 3.3
#define ADC_BITS 4095.0

// Valor médio do circuito de polarização sem carga
#define MIDRAIL_VOLTS 1.5492      

#define FATOR_CALIBRACAO 50.0    


// 1. Detecção do Jack com switch: Leitura zero (GND) é desconectado.
const int LIMIAR_CONEXAO_JACK = 20; 

// 2. Corte de Ruído (TRAVA DE 1 AMPERE)
// Qualquer leitura abaixo de 1.0A será enviada como 0.00A.
// Isso elimina a flutuação dos resistores e garante que o LoRa não envie lixo.
const float CORTE_RUIDO = 1.0;      

unsigned long ultimoTempoLeitura_sct = 0;
const unsigned long intervaloLeitura_sct = 300; 

void setup_sct013() {
    pinMode(PINO_DETECCAO_SCT, INPUT_PULLUP);
    analogReadResolution(12); 
    Serial.println("SCT-013: Ini (Corte < 1A)");
}

float calcular_irms_bruto() {
    double somaQuadrados = 0;
    
    for (int i = 0; i < AMOSTRAS_RMS; i++) {
        int leituraADC = analogRead(PINO_SENSOR_CORRENTE);
        
        // Converte ADC para Tensão
        float tensao = (leituraADC * VREF_ESP) / ADC_BITS;
        
        // Subtrai o Zero Calibrado da sua placa
        float tensaoAC = tensao - MIDRAIL_VOLTS;
        
        // Acumula
        somaQuadrados += (tensaoAC * tensaoAC);
    }
    
    float tensaoRMS = sqrt(somaQuadrados / AMOSTRAS_RMS);
    float corrente = tensaoRMS * FATOR_CALIBRACAO;
    
    // --- TRAVA DE 1 AMPERE ---
    // Se o motor não estiver puxando pelo menos 1A, zera tudo.
    if (corrente < CORTE_RUIDO) {
        corrente = 0.0;
    }
    
    return corrente;
}

bool loop_sct013(DadosSensores &dados) {
    // 1. VERIFICAÇÃO DE CONEXÃO
    // Se o pino 4 estiver zerado (GND), o sensor não está lá.
    int leituraJack = analogRead(PINO_DETECCAO_SCT);
    
    if (leituraJack == 0) {
        dados.corrente = 0.0;
        return false; // Erro Amarelo
    }

    // 2. TEMPO
    if (millis() - ultimoTempoLeitura_sct < intervaloLeitura_sct) {
        return true; 
    }
    ultimoTempoLeitura_sct = millis();

    // 3. LEITURA
    dados.corrente = calcular_irms_bruto();
    
    return true; 
}
#endif
